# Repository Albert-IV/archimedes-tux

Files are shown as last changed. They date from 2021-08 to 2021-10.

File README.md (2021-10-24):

# Archimedes Tux Keyboard

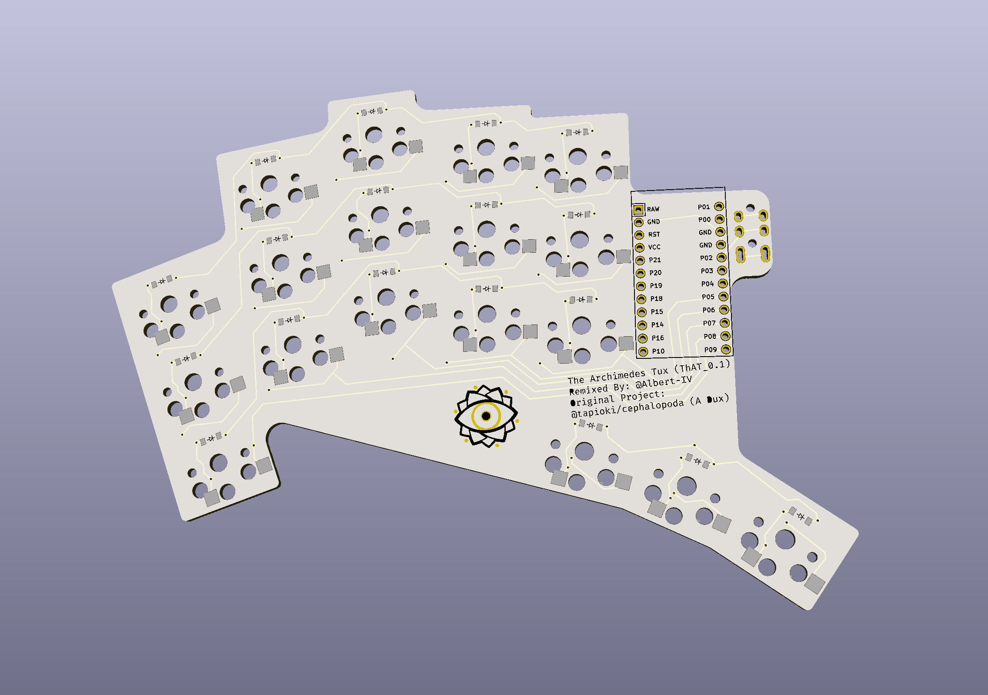
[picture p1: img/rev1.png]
PCB Image


Based off the excellent [Architeuthis Dux keyboard](https://github.com/tapioki/cephalopoda/tree/main/Architeuthis%20dux), the goal is to add a third thumb key and see where else this takes me.

Built with [Ergogen](https://github.com/mrzealot/ergogen).

##### Rev 0.1 - Working!

* AllPCB came back asking about the drilling holes.  Apparently one of them went through one of the TRRS pads, so I told them to just not cut that one out. The rest of the drilling holes are not through any pads or anything important
* PCB's shipped
* PCB's Arrived and Built
* Confirmed working via QMK!

## Rev 0.2

**WIP** - Currently only in `output` folder and completely unrouted.

## Ideas / Goals

- [ ] Make Pro Micro footprint reversible
  - [x]  Add footprint to repo
  - [x]  Rotate footprint
  - [ ]  Add representation of the USB cutout / area
  - [ ]  Change pads / silks to match Ergogen
  - [ ]  Convert Kicad footprint to Erogogen footprint
  - [ ]  Add PR to Erogogen
  - [ ]  Add / place on board
- [ ] Support [[Nice!Nano]] and (possibly) [[BlueMicro]]
  - [ ]  On / Off switch for battery 
  - [ ]  Add battery soldering pads to 
- [ ] Mousebites on third thumb key?
- [ ] Change routing in bottom area to allow for larger silkscreen eye

v0.1 -> v0.2

- [x] Swap pins on row connections to make routing easier
- [x] Add reset switch / pads
- [x] Fix edge cuts / drilling.  (Tapi believes this is an issue due to the multiple fillets / outlines in the Ergogen script)
- [x] Rename repo / files
- [x] Re-add solder locations for switches instead of only hotswap
- [x] Rotate thumbs to allow 1.5u / 2u keycaps
- [x] Re-add Puck support
  - [x]  Add initial footprint to library
  - [x]  Fix text when rotation makes the text apppear in the wrong order
  - [x]  Make each individual screw hole able to be turned on / off
  - [x]  Add PR to Erogogen
  - [x]  Add / place puck on board
- [x] Mousebites on TRRS jack (removable TRRS socket for better [[Nice!Nano]] support)
  - [x] Did it a different way, but the same applies

### To Run Locally

**If you do not have Node.js installed** 

Install using [the installer](https://nodejs.org/en/download/) [NVM,](https://github.com/nvm-sh/nvm) or [Chocolatey](https://community.chocolatey.org/packages/nodejs-lts) depending on your platform.  Using the installer usually leads to permission issues with NPM so it's suggested to use either NVM or chocolatey if you don't want to mess with it too much.

Once this is installed run `npm i -g npm` to upgrade NPM to the latest version.

**After Node.js is installed**

Run `npm run patch-footprints` in the base directory.  This is updates one of the footprints to allow for SMD or through-hole only diodes.

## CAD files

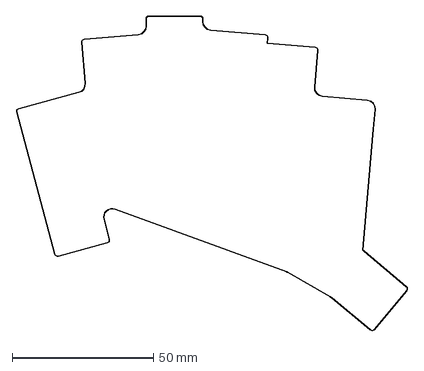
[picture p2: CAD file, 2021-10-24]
output/outlines/first.dxf
138.4 x 111.3 mm

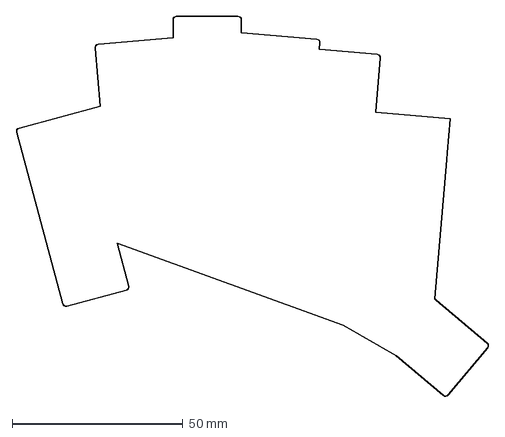
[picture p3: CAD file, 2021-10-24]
output/outlines/raw.dxf
138.4 x 111.3 mm

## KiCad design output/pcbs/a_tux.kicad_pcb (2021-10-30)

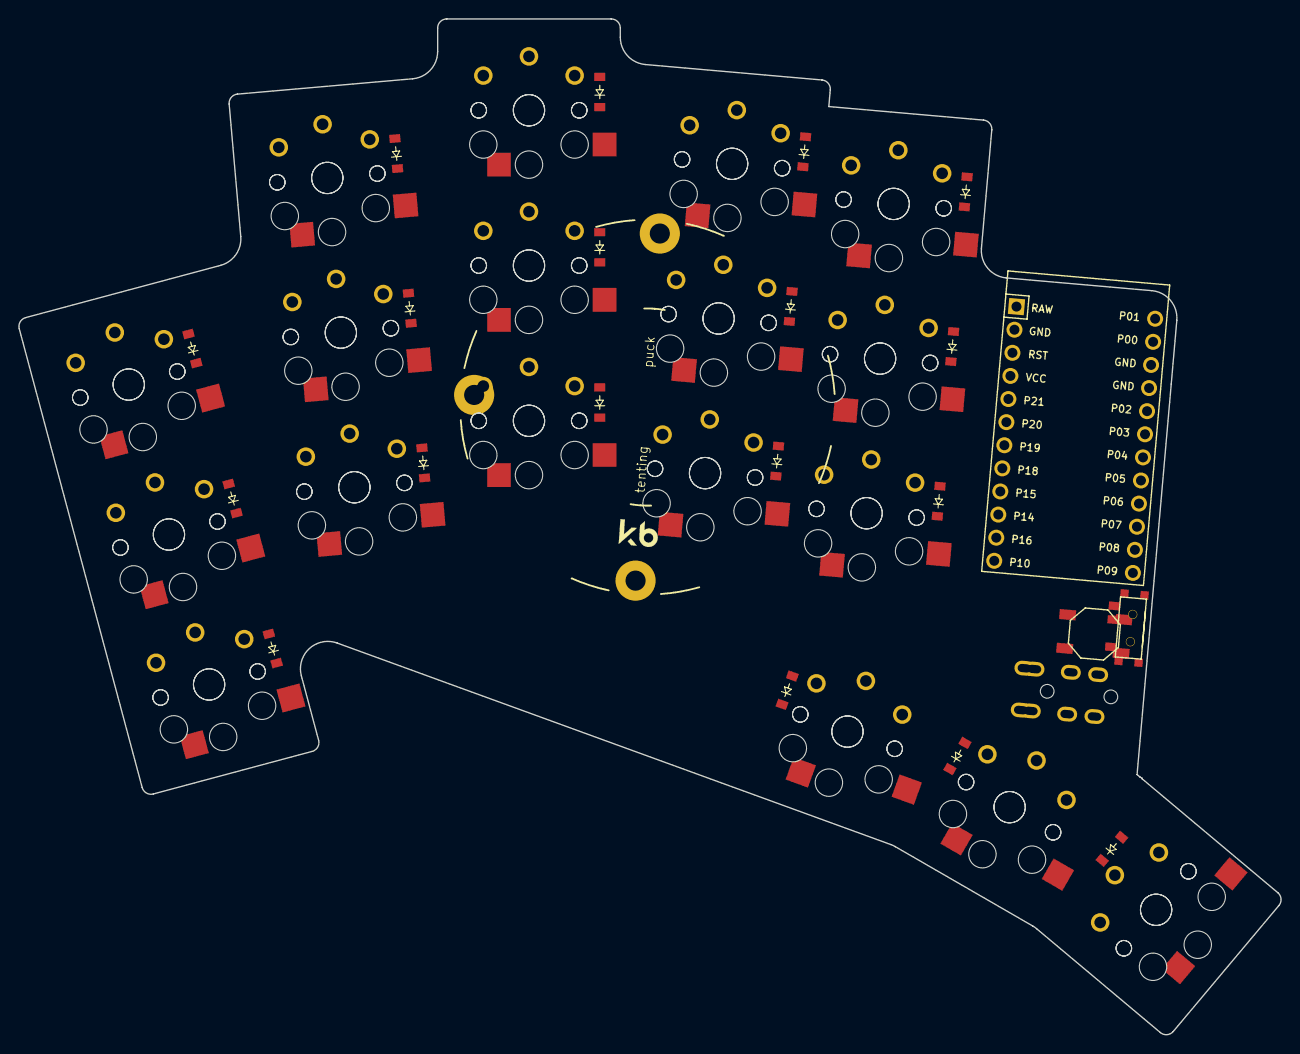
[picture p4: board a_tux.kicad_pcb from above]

Board: 2 copper layers, 138.2 x 111.2 mm, 58 parts (0 on the bottom side), 29 nets, no tracks yet.

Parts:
B1: SW_TACT_ALPS_SKQGABE010
D1, D2, D3, D4, D5, D6, D7, D8, D9, D10, D11, D12, D13, D14, D15, D16, D17, D18: ComboDiode
MCU1: ProMicro
S1, S2, S3, S4, S5, S6, S7, S8, S9, S10, S11, S12, S13, S14, S15, S16, S17, S18, S19, S20, S21, S22, S23, S24, S25, S26, S27, S28, S29, S30, S31, S32, S33, S34, S35, S36: PG1350
T1: SPDT_C128955
_1: Tenting Puck

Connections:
GND: B1.1, MCU1.2, MCU1.15, MCU1.16, T1.1
P5: MCU1.20, S25.2, S26.2, S27.2, S28.2, S29.2, S30.2, S35.2, S36.2
P6: MCU1.21, S19.2, S20.2, S21.2, S22.2, S23.2, S24.2, S33.2, S34.2
P7: MCU1.22, S13.2, S14.2, S15.2, S16.2, S17.2, S18.2, S31.2, S32.2
P8: MCU1.23, S7.2, S8.2, S9.2, S10.2, S11.2, S12.2
P9: MCU1.24, S1.2, S2.2, S3.2, S4.2, S5.2, S6.2
P10: D3.1, D6.1, D9.1, D12.1, D15.1, MCU1.12
P14: D1.1, D4.1, D7.1, D10.1, D13.1, MCU1.10
P15: D16.1, D17.1, D18.1, MCU1.9
P16: D2.1, D5.1, D8.1, D11.1, D14.1, MCU1.11
RST: B1.2, MCU1.3
first_only: D16.2, S31.1, S32.1
index_bottom: D10.2, S19.1, S20.1
index_home: D11.2, S21.1, S22.1
index_top: D12.2, S23.1, S24.1
inner_bottom: D13.2, S25.1, S26.1
inner_home: D14.2, S27.1, S28.1
inner_top: D15.2, S29.1, S30.1
middle_bottom: D7.2, S13.1, S14.1
middle_home: D8.2, S15.1, S16.1
middle_top: D9.2, S17.1, S18.1
pinky_bottom: D1.2, S1.1, S2.1
pinky_home: D2.2, S3.1, S4.1
pinky_top: D3.2, S5.1, S6.1
ring_bottom: D4.2, S7.1, S8.1
ring_home: D5.2, S9.1, S10.1
ring_top: D6.2, S11.1, S12.1
second_only: D17.2, S33.1, S34.1
third_only: D18.2, S35.1, S36.1

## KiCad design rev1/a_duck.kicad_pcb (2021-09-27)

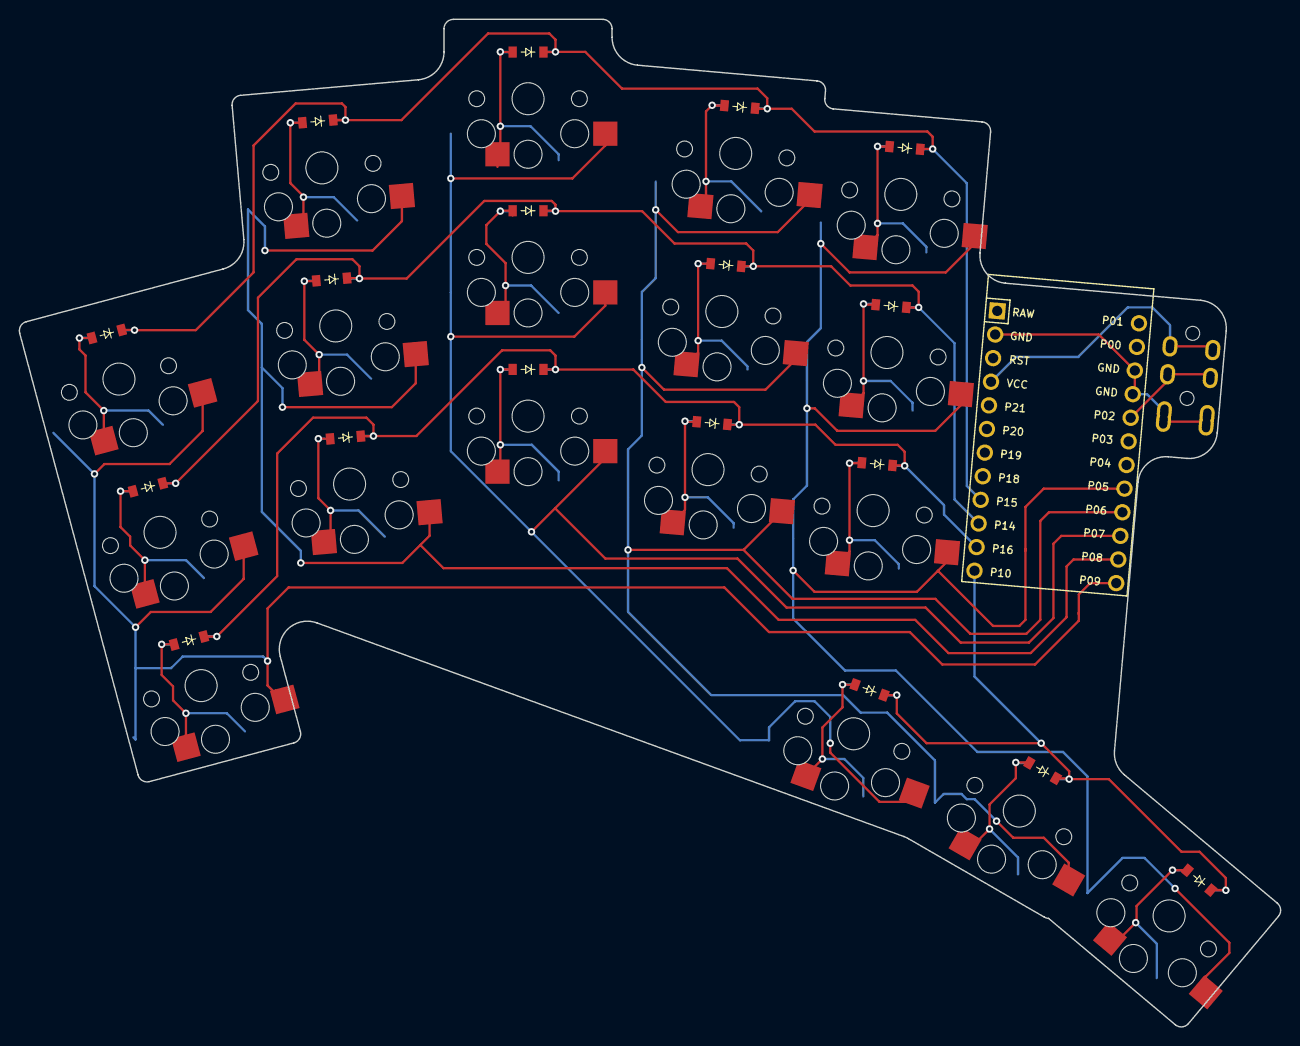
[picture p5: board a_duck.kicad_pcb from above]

Board: 2 copper layers, 135.1 x 107.9 mm, 37 parts (0 on the bottom side), 28 nets.

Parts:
D1, D2, D3, D4, D5, D6, D7, D8, D9, D10, D11, D12, D13, D14, D15, D16, D17, D18: ComboDiode
MCU1: ProMicro
S1, S2, S3, S4, S5, S6, S7, S8, S9, S10, S11, S12, S13, S14, S15, S16, S17, S18: PG1350

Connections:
GND: MCU1.2, MCU1.15, MCU1.16
P5: MCU1.20, S13.2, S14.2, S15.2, S18.2
P6: MCU1.21, S10.2, S11.2, S12.2, S17.2
P7: MCU1.22, S7.2, S8.2, S9.2, S16.2
P8: MCU1.23, S4.2, S5.2, S6.2
P9: MCU1.24, S1.2, S2.2, S3.2
P10: D16.1, D17.1, D18.1, MCU1.12
P14: D2.1, D5.1, D8.1, D11.1, D14.1, MCU1.10
P15: D3.1, D6.1, D9.1, D12.1, D15.1, MCU1.9
P16: D1.1, D4.1, D7.1, D10.1, D13.1, MCU1.11
first_only: D16.2, S16.1
index_bottom: D10.2, S10.1
index_home: D11.2, S11.1
index_top: D12.2, S12.1
inner_bottom: D13.2, S13.1
inner_home: D14.2, S14.1
inner_top: D15.2, S15.1
middle_bottom: D7.2, S7.1
middle_home: D8.2, S8.1
middle_top: D9.2, S9.1
pinky_bottom: D1.2, S1.1
pinky_home: D2.2, S2.1
pinky_top: D3.2, S3.1
ring_bottom: D4.2, S4.1
ring_home: D5.2, S5.1
ring_top: D6.2, S6.1
second_only: D17.2, S17.1
third_only: D18.2, S18.1

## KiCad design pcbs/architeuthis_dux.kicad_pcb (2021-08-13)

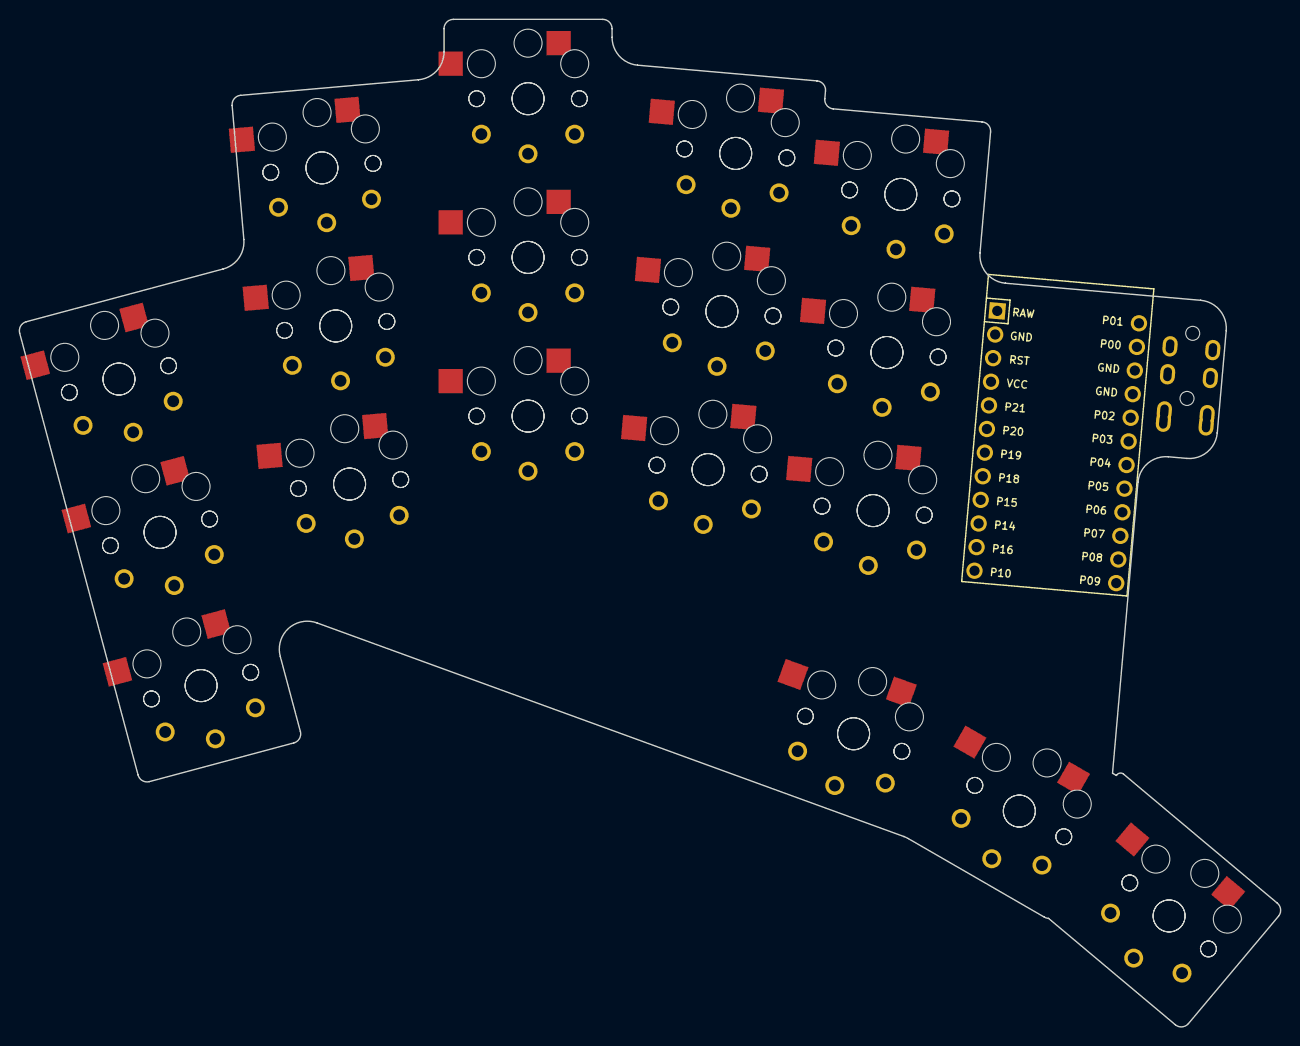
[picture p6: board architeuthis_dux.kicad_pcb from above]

Board: 2 copper layers, 135.1 x 107.9 mm, 37 parts (0 on the bottom side), 18 nets, no tracks yet.

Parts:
MCU1: ProMicro
S1, S2, S3, S4, S5, S6, S7, S8, S9, S10, S11, S12, S13, S14, S15, S16, S17, S18, S19, S20, S21, S22, S23, S24, S25, S26, S27, S28, S29, S30, S31, S32, S33, S34, S35, S36: PG1350

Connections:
GND: MCU1.2, MCU1.15, MCU1.16, S1.2, S2.2, S3.2, S4.2, S5.2, S6.2, S7.2, S8.2, S9.2, S10.2, S11.2, S12.2, S13.2, S14.2, S15.2, S16.2, S17.2, S18.2, S19.2, S20.2, S21.2, S22.2, S23.2, S24.2, S25.2, S26.2, S27.2, S28.2, S29.2, S30.2, S31.2, S32.2, S33.2, S34.2, S35.2, S36.2
P0: MCU1.14, S11.1, S12.1
P1: MCU1.13, S13.1, S14.1
P3: MCU1.18, S9.1, S10.1
P4: MCU1.19, S7.1, S8.1
P5: MCU1.20, S5.1, S6.1
P6: MCU1.21, S3.1, S4.1
P7: MCU1.22, S1.1, S2.1
P8: MCU1.23, S31.1, S32.1
P9: MCU1.24, S33.1, S34.1
P10: MCU1.12, S25.1, S26.1, S35.1, S36.1
P14: MCU1.10, S21.1, S22.1
P15: MCU1.9, S19.1, S20.1
P16: MCU1.11, S23.1, S24.1
P18: MCU1.8, S17.1, S18.1
P19: MCU1.7, S15.1, S16.1
P20: MCU1.6, S27.1, S28.1
P21: MCU1.5, S29.1, S30.1

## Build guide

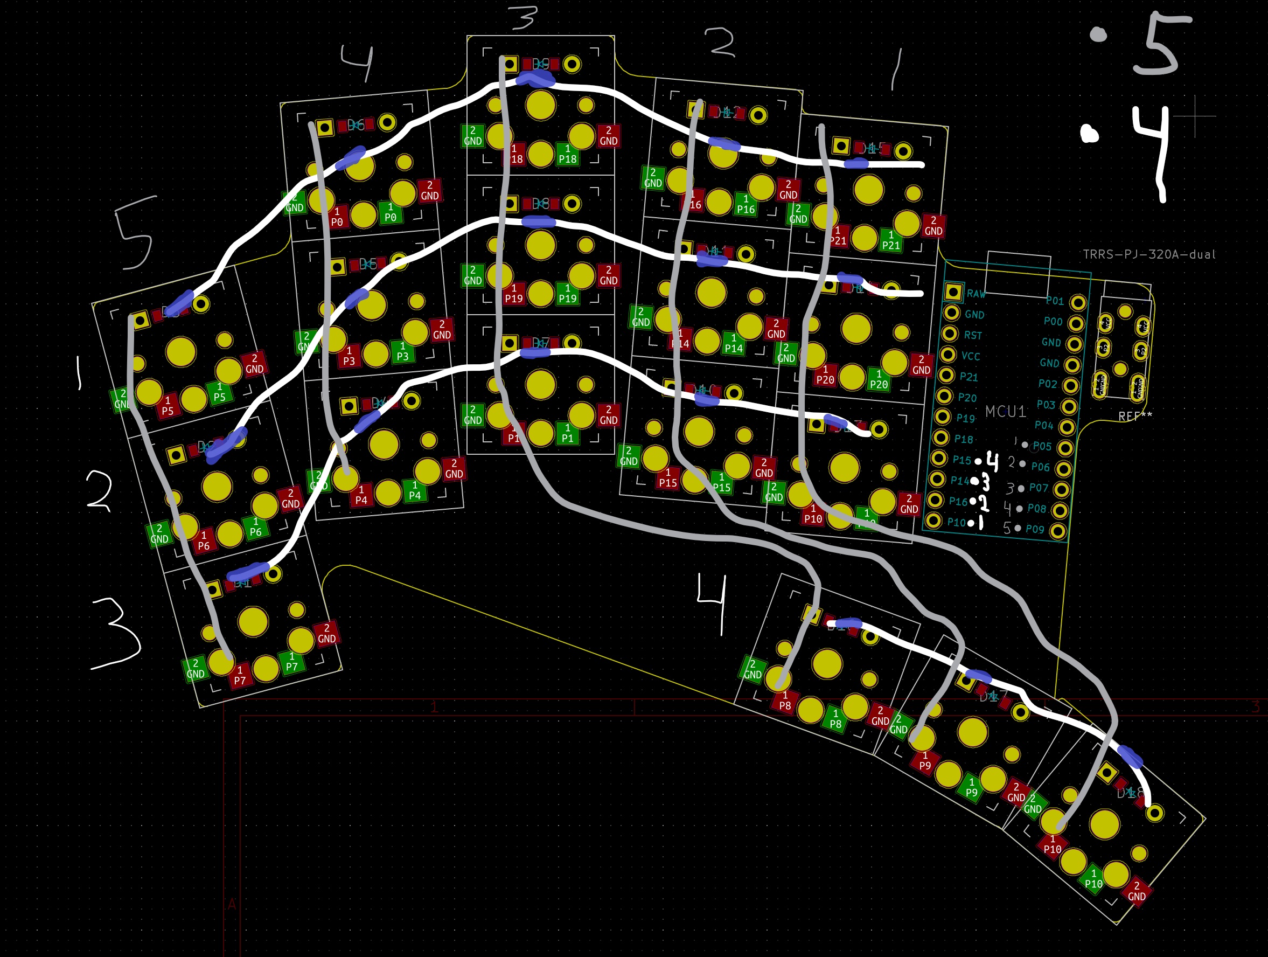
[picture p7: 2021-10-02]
wiring-updated.jpg

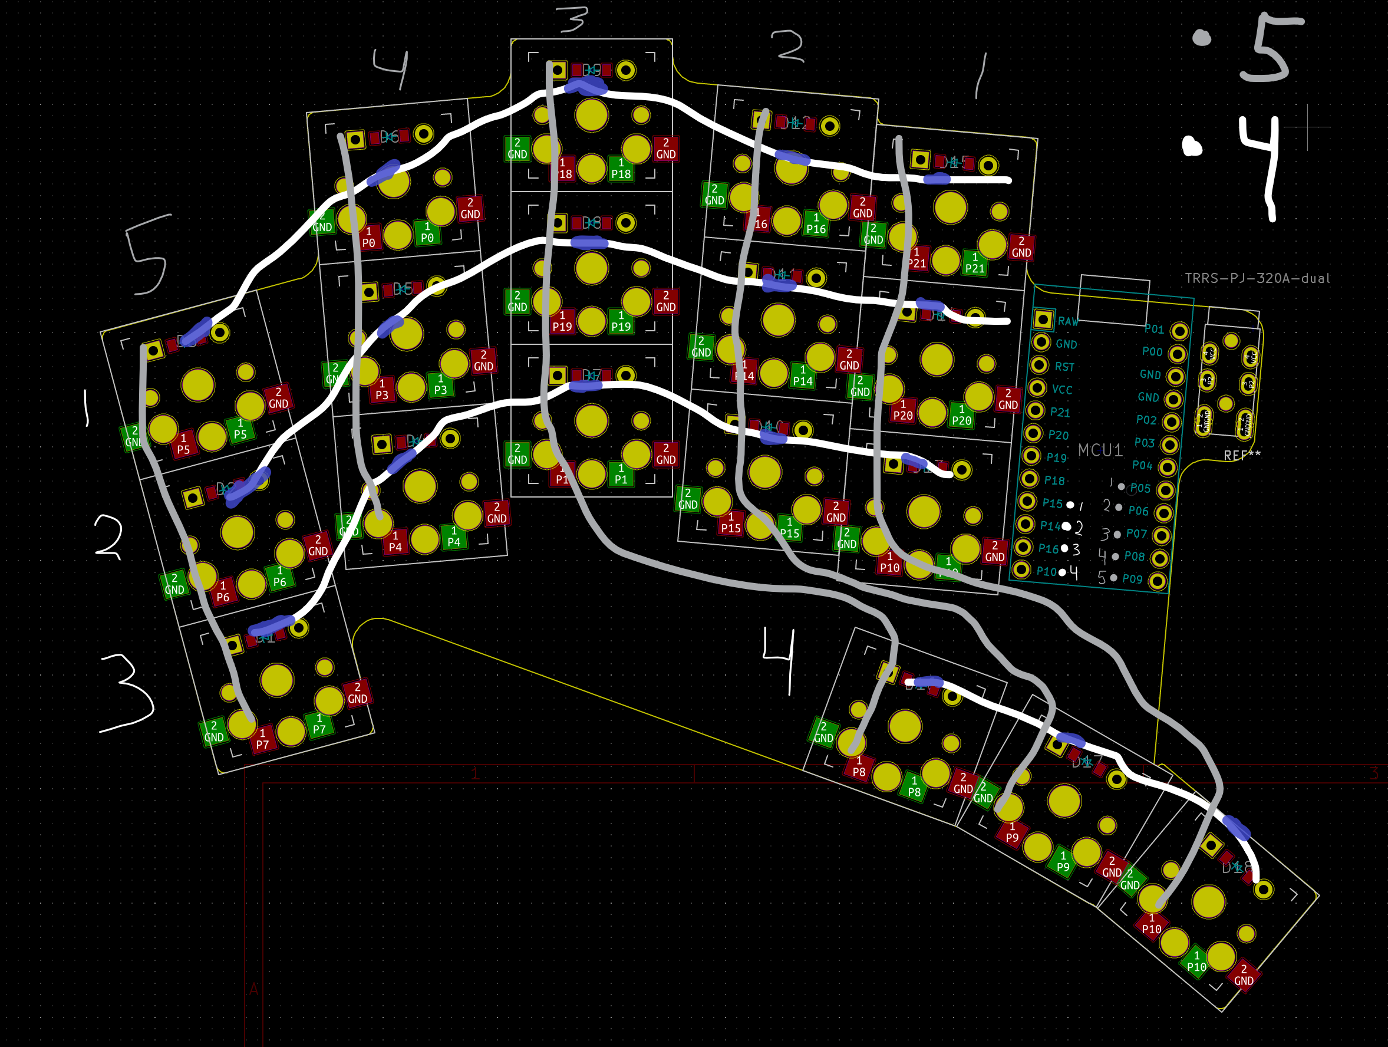
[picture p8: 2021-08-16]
matrix-wiring.png

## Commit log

2021-08-13 Initial commit of WIP.
    [architeuthis_dux.kicad_pcb, demo.dxf, first.dxf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]
2021-08-13 Remove the files put there by the .zip download
    [a_duck.kicad_pcb, architeuthis_dux.kicad_pcb, demo.dxf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]
2021-08-16 Added diodes correctly, removed the non-hotswap locations for now. Added wiring 'guide' to help with setting up the wire map
    [a_duck.kicad_pcb]
2021-08-24 Got the key and diode matrix working!
    [a_duck.kicad_pcb]
2021-08-26 Patch diodes to be SMD only and rotate them for easier routing
    [a_duck.kicad_pcb]
2021-09-27 Added V1 of PCB with routing
    [a_duck.kicad_pcb, first.dxf, panel.dxf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]
2021-09-28 Added PCB silks and footprint files
2021-09-30 Sent PCB off to AllPCB
    [a_duck-B_Cu.gbr, a_duck-B_Mask.gbr, a_duck-B_Paste.gbr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]
2021-10-02 Moved footprints to rev1 folder
2021-10-02 Updated wiring
2021-10-02 Fix outlines / edge cuts of PCB
    [a_duck.kicad_pcb, first.dxf, panel.dxf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]
2021-10-02 Fix left side pins for easier routing
    [a_duck.kicad_pcb]
2021-10-02 Added SMD reset button
    [a_duck.kicad_pcb]
2021-10-02 Rename files to move from A Duck -> Archimedes Tux
    [a_tux.kicad_pcb]
2021-10-03 Added hotswap + solder option for switches, moved diode locations, moved stuff around to make routing easier
    [a_tux.kicad_pcb]
2021-10-04 Rotated the outer thumb for 1.5u or 2u keycap.
    [a_tux.kicad_pcb, first.dxf, raw.dxf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]
2021-10-05 Added Split KB's Puck footprint
    [a_tux.kicad_pcb]
2021-10-09 Add puck back to the PCB, fix puck footprint. Added reversible header footprint
    [a_tux.kicad_pcb]
2021-10-09 Added PCB image
2021-10-24 Added watch scripts, began moving TRRS / pro micro to give myself room
    [a_tux.kicad_pcb]
2021-10-24 Took care of TRRS problem, widened the pro micro space
    [a_tux.kicad_pcb, first.dxf, raw.dxf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]
2021-10-30 Removed reversible pro micro footprint, seems impossible to actually route
    [a_tux.kicad_pcb]
